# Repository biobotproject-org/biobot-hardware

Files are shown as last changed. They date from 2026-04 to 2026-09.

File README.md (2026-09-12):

# biobot-hardware

Hardware for the BioBot wildfire sensor node: an open, low-cost module
placed at the forest edge to catch early signs of smoke. This repository
holds the carrier PCB design, fabrication outputs, and photos of the
assembled board. Firmware lives in
[biobot-firmware](https://github.com/biobotproject-org/biobot-firmware).

Licensed under the CERN Open Hardware Licence v2, Permissive
(CERN-OHL-P-2.0). See `LICENSE.txt`.

## The board: Fire Detection Device, rev A

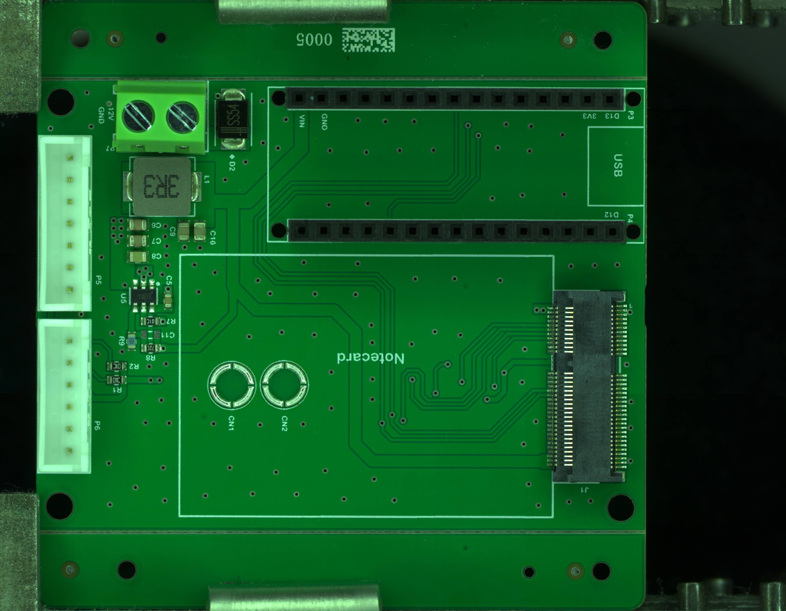
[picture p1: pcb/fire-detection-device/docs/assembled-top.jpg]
Assembled board, top side


Rev A is a carrier board. It does not contain a microcontroller or a
radio of its own; it holds off-the-shelf modules and gives them clean
power and sensor connectors.

| Function | Part | Reference |
| --- | --- | --- |
| Microcontroller | Arduino Nano ESP32 on two 15-pin headers | P3, P4 |
| Cellular modem | Blues Notecard, M.2 Key E socket | J1 |
| External SIM | Nano-SIM push-push holder with ESD protection | J2, D1 |
| Environmental sensor | Bosch BME688 breakout, 6-pin JST-XH | P6 |
| Particulate sensor | Bosch BMV080 breakout, 7-pin JST-XH | P5 |
| Power input | 12 V, 2-pin 5.08 mm screw terminal | P7 |
| 5 V regulator | TI TPS563201 buck, 3 A | U5 |

Schematic dated 15 June 2026, two-layer, assembled by JLCPCB. Source is
an Altium Designer project.

### Connector pinouts

**P5, BMV080 (7-pin JST-XH)**

| Pin | Signal | Notes |
| --- | --- | --- |
| 1 | IRQ | Routed to Nano D2, unused by firmware |
| 2 | AB0 | Address select, not connected |
| 3 | SCL | |
| 4 | SDA | |
| 5 | 3V3 | From the Nano's 3.3 V rail |
| 6 | GND | |
| 7 | AB1 | Address select, not connected |

**P6, BME688 (6-pin JST-XH)**

| Pin | Signal | Notes |
| --- | --- | --- |
| 1 | SCL | |
| 2 | SDA | |
| 3 | 3V3 | |
| 4 | GND | |
| 5 | CSB | Not connected, I2C mode |
| 6 | SDO | Not connected, address set on the breakout |

**P7, power (2-pin screw terminal)**

| Pin | Signal |
| --- | --- |
| 1 | 12 V |
| 2 | GND |

**Nano ESP32 signals used by the board**

| Nano pin | Use |
| --- | --- |
| A4 | I2C SDA, shared by Notecard, BME688, BMV080. 10 kΩ pull-up R1 |
| A5 | I2C SCL. 10 kΩ pull-up R2 |
| D2 | BMV080 IRQ |
| 3V3 | Notecard VIO and both sensor headers |
| VIN | 5 V from the buck regulator |

### Power path

12 V arrives at P7, passes an SS54 Schottky to ground as a reverse
clamp, and feeds the TPS563201. The feedback divider (54.9 kΩ / 10 kΩ)
sets 5.0 V. The 5 V rail feeds the Nano's VIN and the Notecard's
VMODEM pins. Everything at 3.3 V comes from the Nano's onboard
regulator.

The board assumes an external 12 V source, for example a 12 V LiFePO4
battery behind an off-the-shelf solar charge controller with a load
output. There is no charger, no fuel gauge, and no solar input on the
board.

### Known issues, planned for rev B

- No battery voltage sensing. Add a divider from 12 V to a spare ADC pin
  so the node can report battery state.
- The Nano ESP32 VIN pin is specified for 6 to 21 V and is fed 5 V.
  Verify on the bench or move the Nano's supply.
- Reverse polarity protection is a shunt diode with no fuse. Add a
  polyfuse or a P-FET, and a TVS on the 12 V input.
- Notecard ATTN and AUX pins are not routed. ATTN to a GPIO is needed for
  deep-sleep wake.
- No load switch on the sensor 3.3 V rail, so the particulate sensor
  cannot be duty-cycled.
- No antenna provision. The Notecard's u.FL connectors need a pigtail to
  a bulkhead LTE antenna on the enclosure.
- Inductor L1 is labelled "3.3uF" in the schematic and BOM; it is 3.3 µH.
- The schematic title block is blank.

## Ordering

Upload `pcb/fire-detection-device/fabrication/gerber.zip` to JLCPCB and
add `bom.csv` and `pick-and-place.csv` for assembly. Part numbers in the
BOM are LCSC codes. The Nano ESP32, Notecard, SIM, and sensor breakouts
are bought separately and plugged in.

## Repository layout

```
pcb/fire-detection-device/source/       Altium project, schematic, layout, libraries
pcb/fire-detection-device/fabrication/  gerbers, BOM (xlsx and csv), pick-and-place
pcb/fire-detection-device/docs/         schematic PDF, render, assembly photos
archive/kicad-2025-11/                  abandoned first attempt in KiCad, kept for history
```

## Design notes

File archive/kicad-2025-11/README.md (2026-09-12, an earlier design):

# Archived: KiCad sketch, November 2025

The first attempt at a carrier board, drawn in KiCad 9. It contains only a
Nano ESP32 module, an M.2 socket for the Notecard, a TCA9548A I2C
multiplexer, and one capacitor. The board file is empty; layout was
started and abandoned on 12 November 2025 (see the backups folder).

It was superseded by the Altium "Fire Detection Device" board in
`pcb/fire-detection-device/`. Kept for history only.

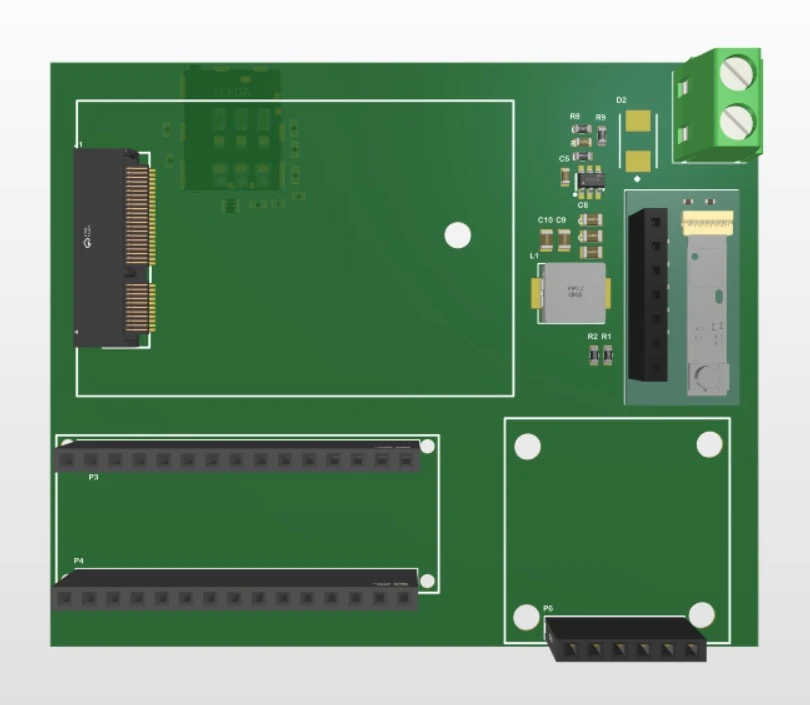
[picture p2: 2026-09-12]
pcb/fire-detection-device/docs/render-top.webp

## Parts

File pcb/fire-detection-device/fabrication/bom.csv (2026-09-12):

Comment | Designator | Footprint | Quantity | Part Number
0.1uF | C5 | Ceramic capacitor (0603) | 1 | C14663
0.1uF | C8 | Ceramic capacitor (0805) | 1 | C519981
3.3uF | L1 | IND-SMD_L7.3-W6.6 | 1 | C128687
10K | R1, R2 | Resistor (0603) | 2 | C191124
10K | R5 | Resistor (0402) | 1 | C427247
10K | R7 | Resistor (0603) | 1 | C136139
10K | R9 | Resistor (0603) | 1 | C130232
10uF | C6, C7 | Ceramic capacitor (0805) | 2 | C15850
22R | R3, R4, R6 | Resistor (0402) | 3 | C25092
22uF | C9, C10 | Ceramic capacitor (0805) | 2 | C296720
33pF | C2, C3, C4 | Ceramic capacitor (0402) | 3 | C107005
54.9K | R8 | Resistor (0603) | 1 | C185321
100nF | C1 | Ceramic capacitor (0402) | 1 | C1525
9774025151R | CN1, CN2 | SMD-1_BD5.1-D3.5 | 2 | C7496631
B6B-XH-A(LF)(SN) | P6 | CONN-TH_6P-P2.50_B6B-XH-A-LF-SN | 1 | C144397
B7B-XH-A(LF)(SN) | P5 | CONN-TH_7P-P2.50_B7B-XH-A-LF-SN | 1 | C144398
KF127-5.08-2P | P7 | CONN-TH_P5.08_KF127-5.08-2P | 1 | C474906
KH-2.54FH-1X15P-H8.5 | P3, P4 | HDR-TH_15P-P2.54-V-F | 2 | C2932676
MDT420E01001 | J1 | CONN-SMD_67P-P0.50_TE_2199119-6 | 1 | C4529147
PESD5V0L5UV,115 | D1 | SOT-666-6_L1.6-W1.2-P0.50-LS1.6-TL | 1 | C84255
SF72S006VBDR2500 | J2 | NANO-SIM-SMD_SMN-315-ARP7 | 1 | C2977286
SS54(SMB) | D2 | FP_SS54(SMB) | 1 | C4154972
TPS563201DDCR | U5 | SOT-23-6_L2.9-W1.6-P0.95-LS2.8-BR | 1 | C116592

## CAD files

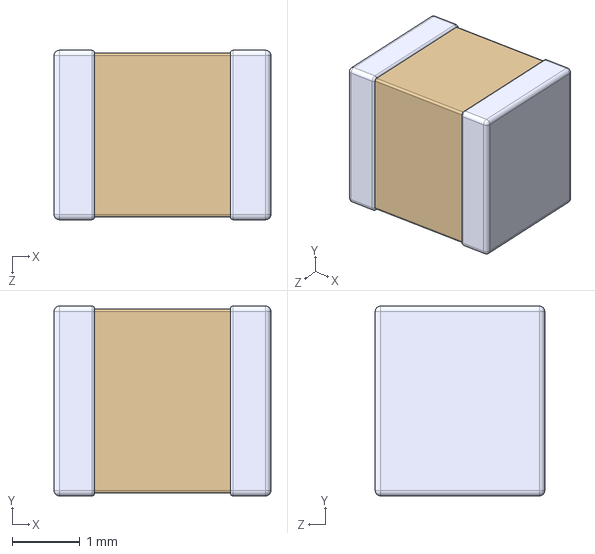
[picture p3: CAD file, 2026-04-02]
guh/CL32A227MQVNNNE.step
3.20 x 2.80 x 2.50 mm

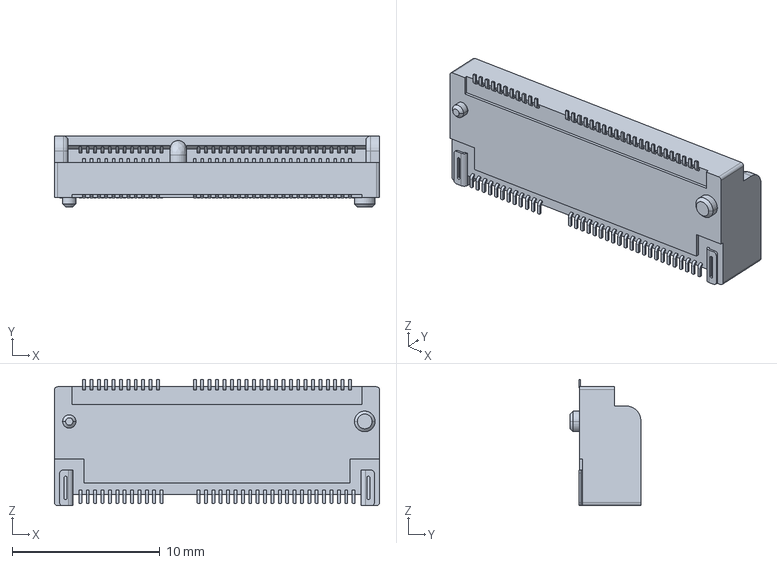
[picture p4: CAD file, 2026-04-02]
guh/MDT420E02001/MDT420E02001.step
22.0 x 4.80 x 8.55 mm

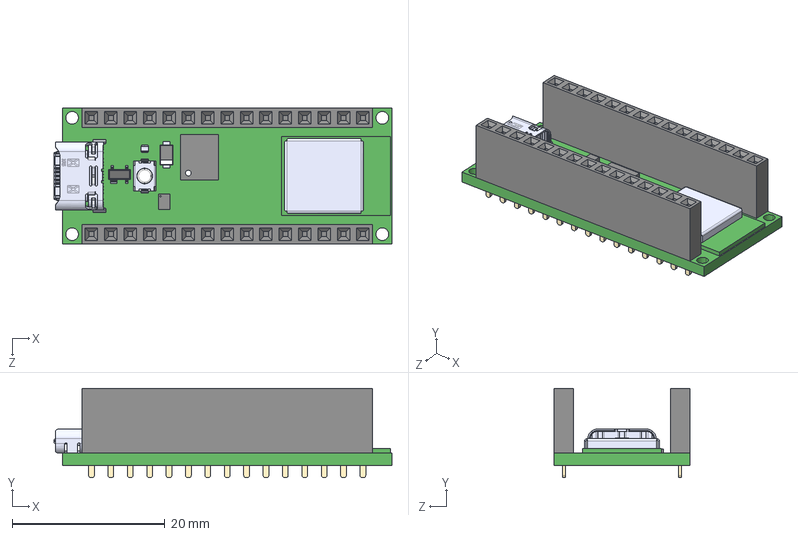
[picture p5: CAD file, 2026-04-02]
guh/NANO-ESP32-ENTRY/NANO-ESP32-ENTRY.step
44.3 x 11.7 x 17.8 mm
ABX00083 - board
CX90B-16P_3D-0.stp
NORA-W106
PRTR5V0U2X
PMEG6020AELRX
PTS820J20KSMTRLFS
SMLP34RGB2W3
other^ABX00083
MP2322GQH
Header JP x 2

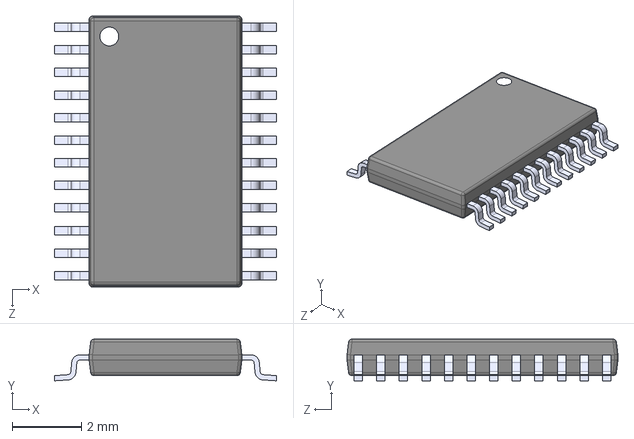
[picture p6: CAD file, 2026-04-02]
guh/TCA9548APWR/TCA9548APWR.step
6.40 x 1.20 x 7.80 mm

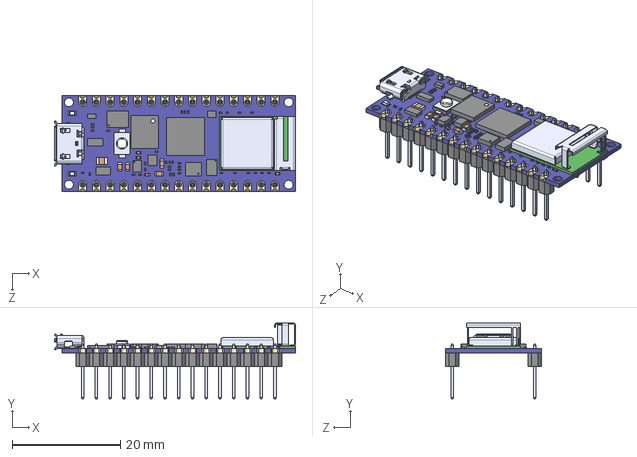
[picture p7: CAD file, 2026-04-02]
guh/ABX00053/ABX00053.step
44.6 x 14.0 x 17.8 mm

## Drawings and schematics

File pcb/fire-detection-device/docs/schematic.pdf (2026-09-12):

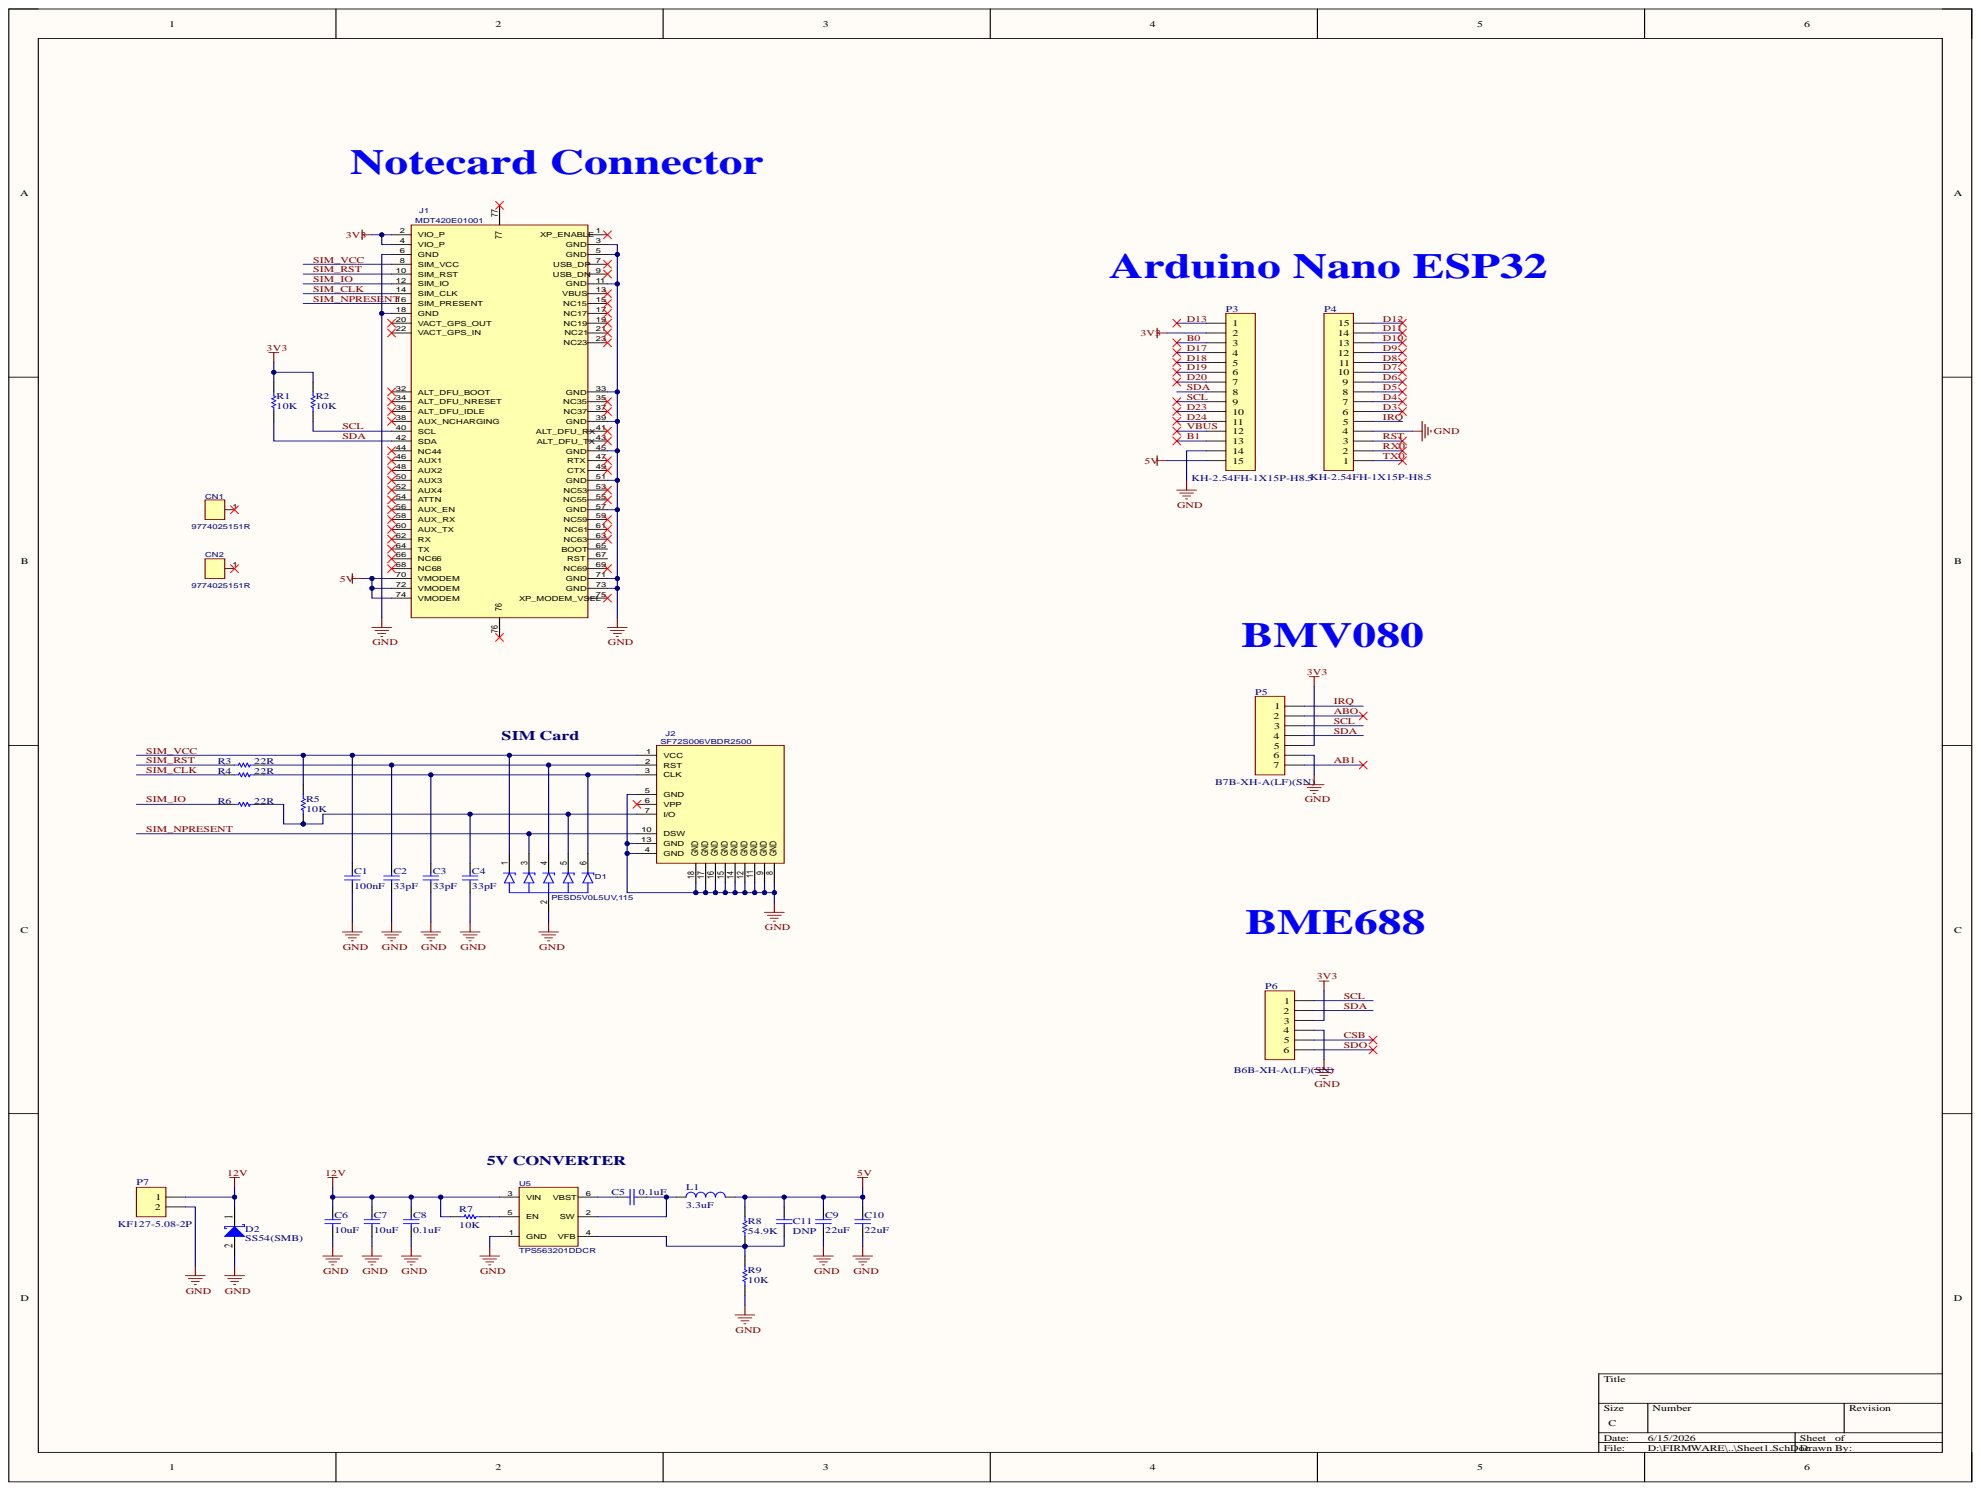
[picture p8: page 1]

RST 2
CLK 3

GND 5

GND 14 GND 15 GND 16 GND 17 GND 18

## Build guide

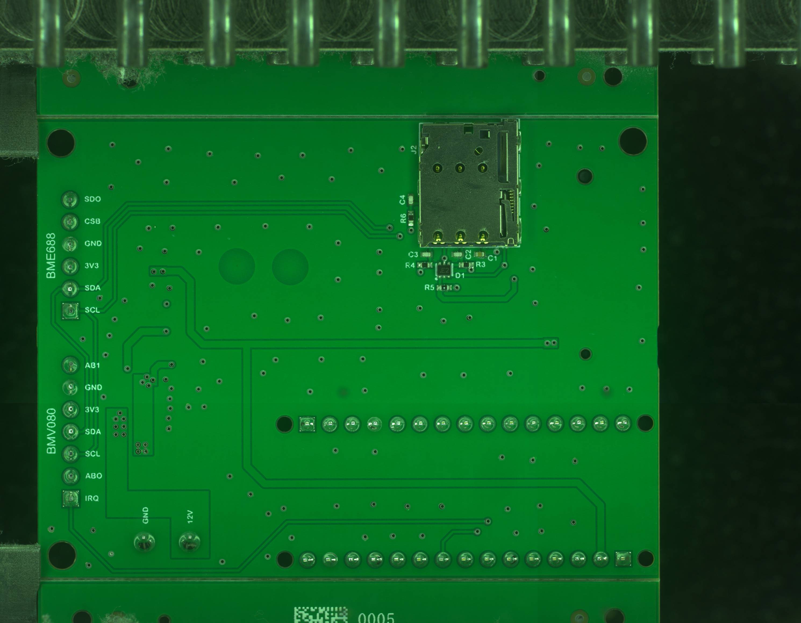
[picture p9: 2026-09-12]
pcb/fire-detection-device/docs/assembled-bottom.jpg

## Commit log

2026-04-02 Initial commit: add project files
    [ABX00053.step, CL32A227MQVNNNE.step, MDT420E02001.step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]
2026-09-12 Add the Fire Detection Device carrier board and relicense under CERN-OHL-P
    - Add the Altium source, gerbers, BOM (xlsx and a diffable csv),
    pick-and-place files, schematic PDF, render, and JLCPCB assembly
    photos for the rev A carrier board (schematic dated 15 June 2026).
    - Move the abandoned November 2025 KiCad sketch and its downloaded
    libraries under archive/ with a note; drop editor lock files.
    - Replace the Apache-2.0 software license with CERN-OHL-P-2.0, a
    hardware license.
    - Write a README with the board's function, connector pinouts, power
    path, known issues planned for rev B, and ordering steps.
    Claude-Session: https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
    [Fire Detection Device.PrjPcb, PCB1.PcbDoc, PcbLib1.PcbLib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]
2026-10-26 Add the pipe-enclosure sled as a Fusion script
    Sled for a 6-inch Schedule 40 PVC tube, generated parametrically: a
    plate with rails and printed standoffs for the PCB (from the gerber
    hole positions) and the Victron 75/15 (measured), strap slots for the
    battery, and two bulkhead discs that centre it in the tube and carry
    the sensors on the nose. Three bodies, each printing flat without
    supports.
    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
